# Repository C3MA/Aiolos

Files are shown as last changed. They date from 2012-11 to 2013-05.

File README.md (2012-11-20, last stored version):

avr-template
============

A minimal template for AVR microcontroller projects. Usage:

1. Fork this repository, then rename it to reflect your project
(Admin->Rename on Github)
2. Clone your repository
3. Change the Makefile to reflect your microcontroller, programmer etc.

### License

The UART code is written by Peter Fleury. Everything else: BSD 2-clause
license as below:

Copyright (c) 2012, Mathias Dalheimer
All rights reserved.

Redistribution and use in source and binary forms, with or without
modification, are permitted provided that the following conditions are
met:

* Redistributions of source code must retain the above copyright notice, 
this list of conditions and the following disclaimer.

* Redistributions in binary form must reproduce the above copyright
notice, this list of conditions and the following disclaimer in the
documentation and/or other materials provided with the distribution.

THIS SOFTWARE IS PROVIDED BY THE COPYRIGHT HOLDERS AND CONTRIBUTORS "AS
IS" AND ANY EXPRESS OR IMPLIED WARRANTIES, INCLUDING, BUT NOT LIMITED
TO, THE IMPLIED WARRANTIES OF MERCHANTABILITY AND FITNESS FOR A
PARTICULAR PURPOSE ARE DISCLAIMED. IN NO EVENT SHALL THE COPYRIGHT
HOLDER OR CONTRIBUTORS BE LIABLE FOR ANY DIRECT, INDIRECT, INCIDENTAL,
SPECIAL, EXEMPLARY, OR CONSEQUENTIAL DAMAGES (INCLUDING, BUT NOT
LIMITED TO, PROCUREMENT OF SUBSTITUTE GOODS OR SERVICES; LOSS
OF USE, DATA, OR PROFITS; OR BUSINESS INTERRUPTION) HOWEVER
CAUSED AND ON ANY THEORY OF LIABILITY, WHETHER IN CONTRACT,
STRICT LIABILITY, OR TORT (INCLUDING NEGLIGENCE OR OTHERWISE)
ARISING IN ANY WAY OUT OF THE USE OF THIS SOFTWARE, EVEN IF ADVISED OF
THE POSSIBILITY OF SUCH DAMAGE.

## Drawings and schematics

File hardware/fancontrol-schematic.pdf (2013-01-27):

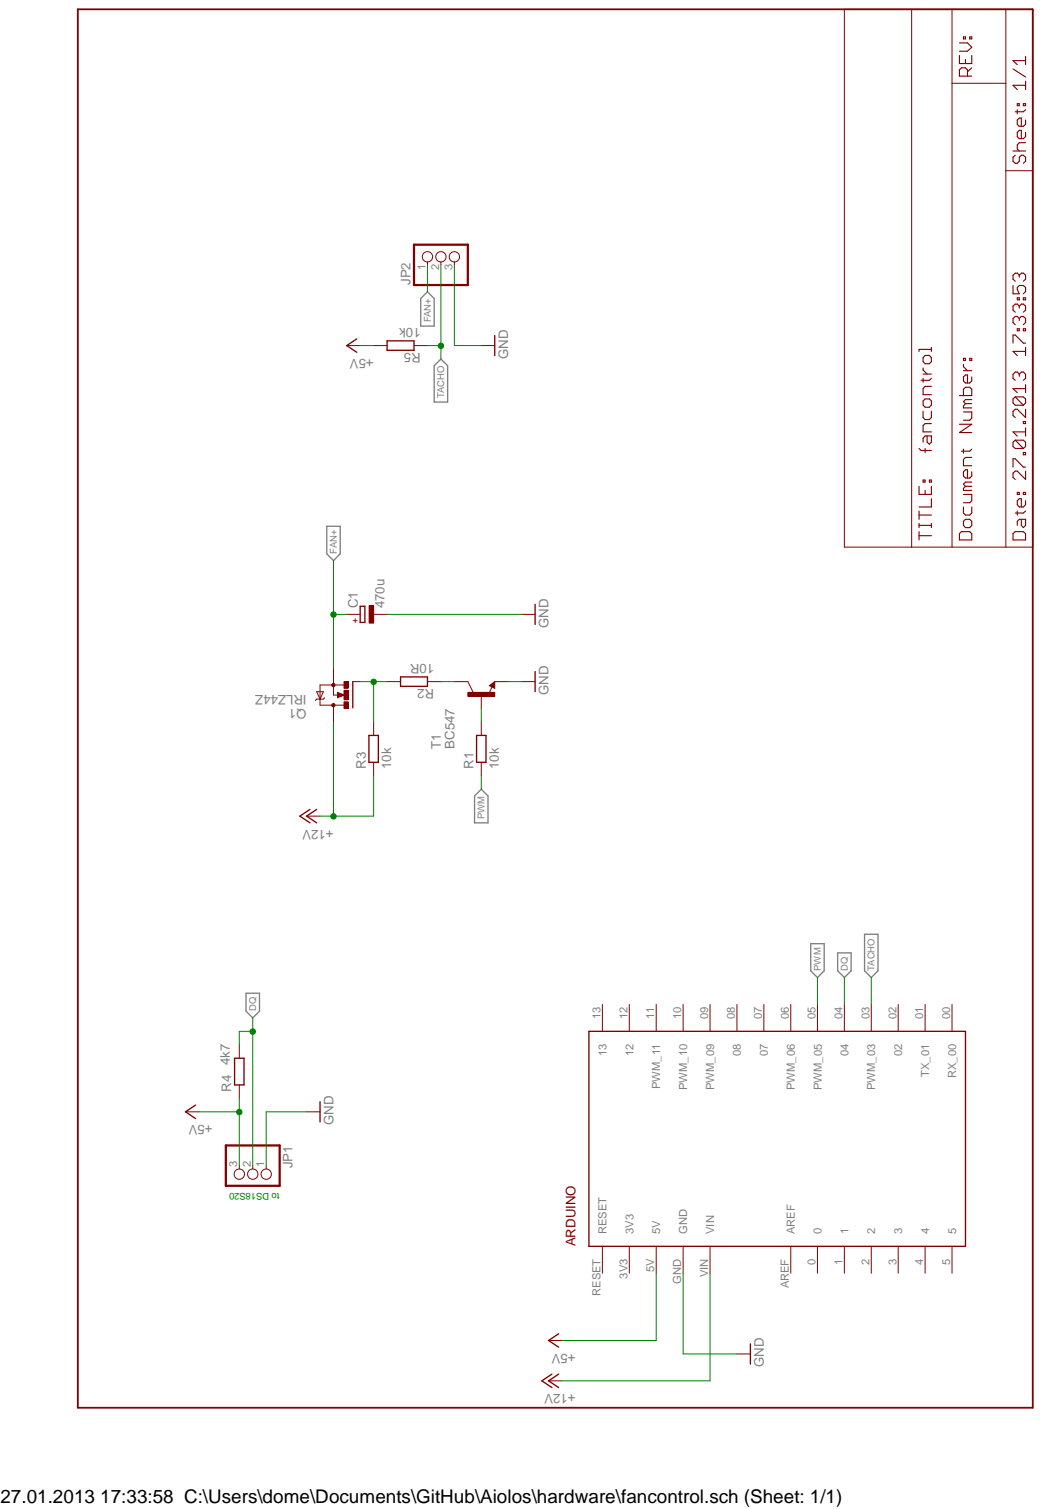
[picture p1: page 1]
GND; RESET RESET; GND GND; VIN VIN; AREF AREF; PWM_11 11; PWM_10 10; PWM_09 09; PWM_06 06; PWM_05 05; PWM_03 03; FAN+; TACHO; PWM; ARDUINO

27.01.2013 17:33:58 C:\Users\dome\Documents\GitHub\Aiolos\hardware\fancontrol.sch (Sheet: 1/1)

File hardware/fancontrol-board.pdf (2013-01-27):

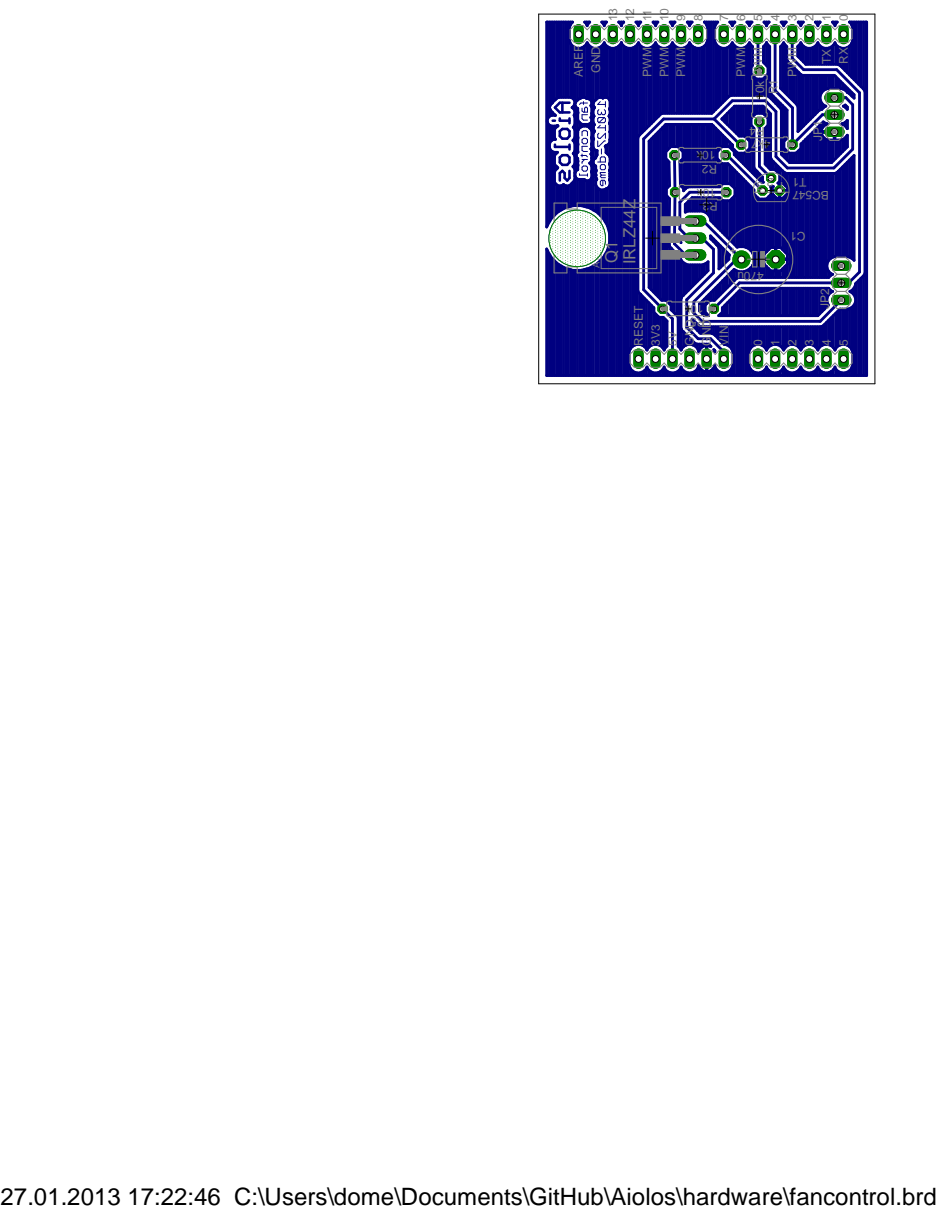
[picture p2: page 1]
27.01.2013 17:22:46 C:\Users\dome\Documents\GitHub\Aiolos\hardware\fancontrol.brd A¹⁷,5mm; RESET; GND GND VIN; AREF; GND; PWM; IRLZ44Z

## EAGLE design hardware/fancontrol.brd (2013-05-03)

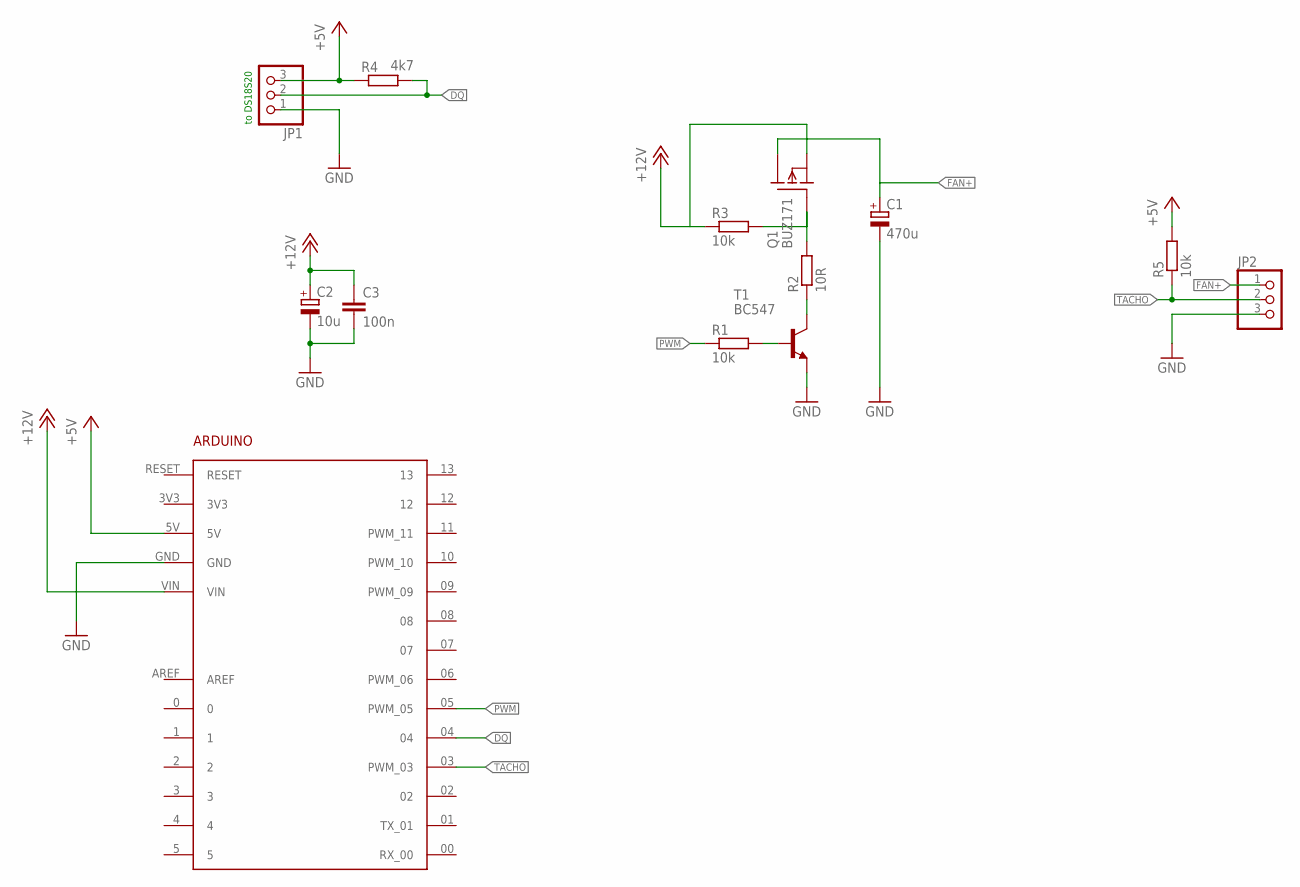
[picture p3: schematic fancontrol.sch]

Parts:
ARDUINO1: ARDUINO
C1: 470u; E5-10,5
C2: 10u; E2,5-5
C3: 100n; C025-025X050
JP1, JP2: PINHD-1X3; 1X03
Q1: BUZ171; TO220
R1, R3, R5: 10k; 0207/7
R2: 10R; 0207/7
R4: 4k7; 0207/7
T1: BC547; TO92

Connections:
+5V: ARDUINO1.5V, JP1.3, R4.1, R5.2
+12V: ARDUINO1.VIN, C2.+, C3.1, Q1.3 (S), R3.1
DQ: ARDUINO1.04, JP1.2, R4.2
FAN+: C1.+, JP2.1, Q1.2 (D)
GND: ARDUINO1.GND, C1.-, C2.-, C3.2, JP1.1, JP2.3, T1.1 (E)
unnamed: R1.2, T1.2 (B)
unnamed: R2.1, T1.3 (C)
unnamed: Q1.1 (G), R2.2, R3.2
PWM: ARDUINO1.05 (PWM_05), R1.1
TACHO: ARDUINO1.03 (PWM_03), JP2.2, R5.1

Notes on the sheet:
to DS18S20

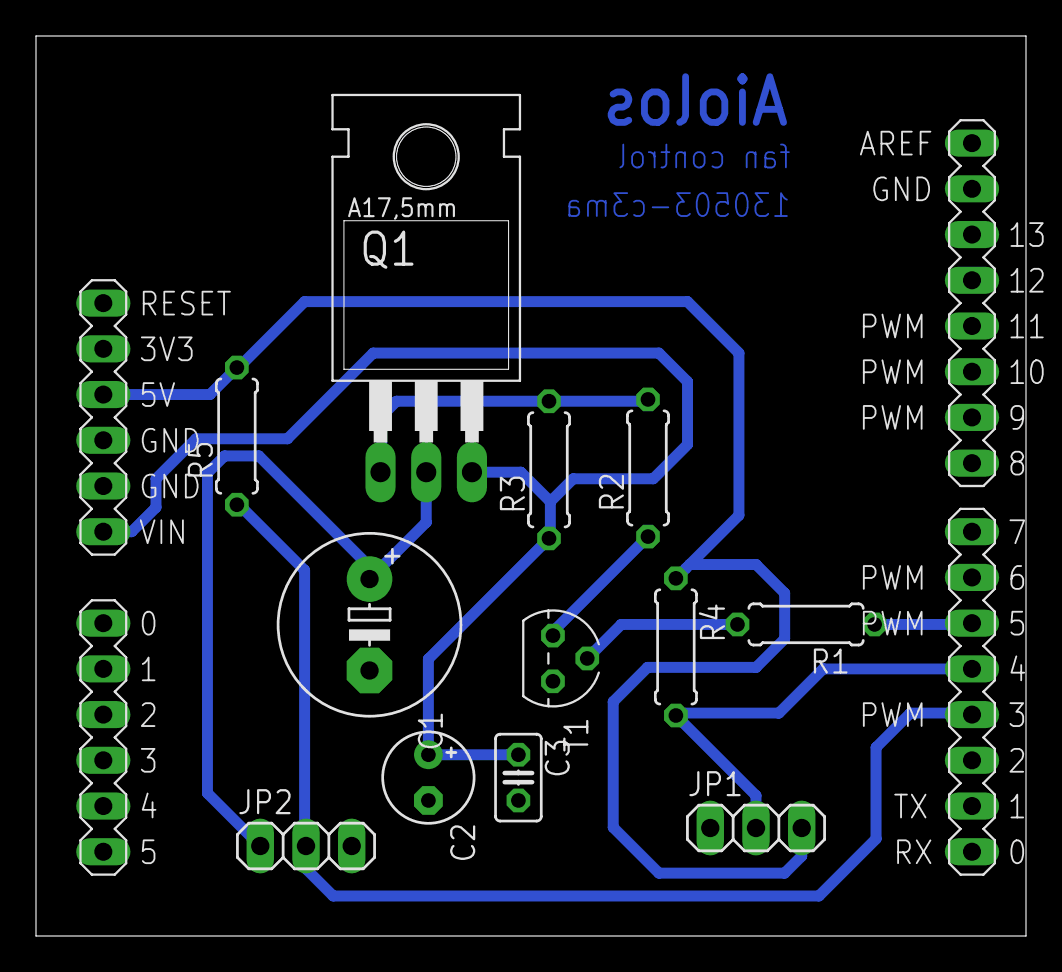
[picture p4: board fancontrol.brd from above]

Board: 2 copper layers, 55.0 x 50.0 mm, 13 parts (0 on the bottom side), 10 nets.

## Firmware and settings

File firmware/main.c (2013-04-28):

#include <stdlib.h>
#include <avr/io.h>
#include <avr/interrupt.h>
#include <avr/pgmspace.h>
#include <stdio.h>



#include "uart.h"
#include "temperature.h"

int uart_putchar( char c, FILE *stream )
{
    if( c == '\n' )
        uart_putchar( '\r', stream );
 
    uart_putc(c);

    return 0;
}

static FILE mystdout = FDEV_SETUP_STREAM( uart_putchar, NULL, _FDEV_SETUP_WRITE );

/* define CPU frequency in Mhz here if not defined in Makefile */
#ifndef F_CPU
#define F_CPU 16000000UL
#endif

/* 115200 baud  Arduino bootlaoder macht das x2 deshalb 57600 */
#define UART_BAUD_RATE      57600      

/* counter for tacho */
volatile uint8_t tachoCounter = 0;

volatile uint8_t flag = 0;


#define Kp 40.0
#define Ki 0.0
#define Kd 0.0

double PID_Berechnung (double x, double w)
{ 
static double ealt;
double e,esum,y; 

e = x - w;                // aktuelle Regelabweichung bestimmen
if ((y < 1023)&&(y > 0))  // bei Übersteuertem stellglied Integration einfrieren
  {                       // (Anti-Windup)
    esum = esum + e;      // Summe der Regelabweichung aktualisieren  
  }
y = (Kp*e)+(Ki*esum)+(Kd*((e-ealt))/1);  // Reglergleichung
ealt = e;                 // Regelabweichung für nächste Abtastung merken
if (y > 256)             // Stellgröße auf 0..1023 begrenzen (10 bit PWM)
  {
    y = 255;
  }
if (y < 1)
  {
    y = 0;
  }
return y;                 // Stellgröße zurückgeben
}

int main(void)
{

    unsigned int c;
    char buffer[7];
    int  num=134;
    
    /*
     * Init Timer 1; 1s cycle
     */
    
    TCCR1A = 0x0;
    TCCR1B = (1<<WGM12) | (1<<CS12) | (1<<CS10);
    OCR1AH = 0x3D;
    OCR1AL = 0x08;
    TIMSK1 |= (1<<OCIE1A);
    
    /* Init PWM */
    PRR &= ~(1<<PRTIM0);
    DDRD |= (1<<PD5); // Port OC0B 
    TCCR0A = (1<<WGM10) | (1<<COM0B1); // PWM, phase correct, 8 bit.
    TCCR0B = (1<<CS12) | (1<<CS10); // Prescaler 1024 = Enable counter
    OCR0B = 240; // Duty cycle 50% (Anm. ob 128 oder 127 bitte prüfen) 
    
    /*
     *  Initialize UART library, pass baudrate and AVR cpu clock
     *  with the macro 
     *  UART_BAUD_SELECT() (normal speed mode )
     *  or 
     *  UART_BAUD_SELECT_DOUBLE_SPEED() ( double speed mode)
     */
    uart_init( UART_BAUD_SELECT(UART_BAUD_RATE,F_CPU) ); 
    stdout = &mystdout;

    /* Init INT 1 Tacho */
    EIMSK |= (1<<INT1);
    EICRA |= (1<<ISC11) | (1<<ISC10); 

    /*
     * now enable interrupt, since UART library is interrupt controlled
     */
    sei();

    temperature_init();

    for(;;)
    {
        if (flag == 1)
	{
	    flag = 0;
	    uint8_t tcount = tachoCounter;
	    tachoCounter = 0;
	    
	    /*if (temp >= 30)
	    {
		OCR0B = 0;
	    } 
	    else if(temp >= 28.0)
	    {
		OCR0B = 200;
	    }
	    else
	    {
		OCR0B = 250;
	    }*/
	   
	    
	    /*
	    if (y < 1)
	    {
	      y = 0;
	    }*/
	    
	    OCR0B = (uint8_t)  PID_Berechnung((double) temperature_get(), 26.0);
	    
	    printf("%s;%d;%d\r\n",temperature_as_string(), tcount * 30, OCR0B);
	    /*
	    printf("Current temp: %s deg C\r\n", temperature_as_string());
	    printf("Current speed: %d rpm\r\n", tcount * 30);
	    */
	}
    }
    
}

ISR(TIMER1_COMPA_vect)
{
   flag = 1;
}

ISR(INT1_vect )
{
  tachoCounter++;
}

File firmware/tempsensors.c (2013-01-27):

/**
 * This file is part of C8H10N4O2.
 *
 * (c) Mathias Dalheimer <md@gonium.net>, 2010
 * This file is based on  Martin Thomas' DS18X20 library
 *  http://gandalf.arubi.uni-kl.de/avr_projects/tempsensor/index.html
 *
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
 */

#include <avr/io.h>
#include <avr/pgmspace.h>
#include <avr/interrupt.h>
#include <string.h>

#include "tempsensors.h"
#include "onewire.h"
#include "ds18x20.h"

uint8_t nSensors, i;
volatile int16_t decicelsius;
volatile int32_t temp_eminus4;
uint8_t error;
uint8_t gSensorIDs[MAXSENSORS][OW_ROMCODE_SIZE];

uint32_t starttime;

uint8_t search_sensors(void) {
  uint8_t i;
  uint8_t id[OW_ROMCODE_SIZE];
  uint8_t diff, nSensors;
  ow_reset();
  nSensors = 0;
  diff = OW_SEARCH_FIRST;
  while ( diff != OW_LAST_DEVICE && nSensors < MAXSENSORS ) {
	DS18X20_find_sensor( &diff, &id[0] );
	if( diff == OW_PRESENCE_ERR ) {
	  break;
	}
	if( diff == OW_DATA_ERR ) {
	  break;
	}
	for ( i=0; i < OW_ROMCODE_SIZE; i++ )
	  gSensorIDs[nSensors][i] = id[i];
	nSensors++;
  }
  return nSensors;
}

void uart_put_temp(int16_t decicelsius) {
  char s[10];
  //uart_put_int( decicelsius );
  printf("%d", (int) decicelsius );
  printf(" deci°C, ");
  DS18X20_format_from_decicelsius( decicelsius, s, 10 );
  printf( s );
  printf(" °C");
}

int16_t getTemperature(void) {
  return decicelsius;
}

int32_t getHighResTemperature(void) {
  return temp_eminus4;
}

float getTemperatureFloat(void) {
  return (temp_eminus4/10000.0);
}
#if DS18X20_MAX_RESOLUTION

void uart_put_temp_maxres(int32_t tval) {
  char s[10];

  //uart_put_longint( tval );
  printf("%d", (int )tval );
  printf(" °Ce-4, ");
  DS18X20_format_from_maxres( tval, s, 10 );
  printf( s );
  printf(" °C");
}

#endif /* DS18X20_MAX_RESOLUTION */

uint8_t initTempSensors(void) {
  printf("Searching for OneWire temperature sensors.\n" );
  nSensors = search_sensors();
  return nSensors;
}	

void loopTempSensors(void) {
  error = 0;

  if ( nSensors == 0 ) {
    error++;
  }

  if ( DS18X20_start_meas( DS18X20_POWER_PARASITE, NULL ) 
      == DS18X20_OK) {

    for ( i = 0; i < nSensors; i++ ) {
      if ( DS18X20_read_maxres( &gSensorIDs[i][0], &temp_eminus4 )
          == DS18X20_OK ) {
        ;; // we're cool - read a value.
        //uart_put_temp_maxres( temp_eminus4 );
      }
      else {
        error++;
      }
    }
  } else {
    error++;
  }

  if ( error ) {
    nSensors = search_sensors();
    //uart_put_int( (int) nSensors );
    error = 0;
  }
}

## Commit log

2013-01-27 first prototype firmware for the temperature control of der Schrank
2013-01-27 empty schematic
    [fancontrol.sch]
2013-01-27 fan control
    [fancontrol.sch]
2013-01-27 generated board
    [fancontrol.brd, fancontrol.sch]
2013-01-27 populated the pcb
    [fancontrol.brd, fancontrol.sch]
2013-01-27 finished the routung
    [fancontrol.brd]
2013-01-27 added version number
    [fancontrol.brd]
2013-01-27 changed R2 from 10k to 10R
    [fancontrol.brd, fancontrol.sch]
2013-02-20 connect JP2 to GND. Fixes #2
    [fancontrol.brd, fancontrol.sch]
2013-02-20 added capacitors to Vin. Fixes #1
    [fancontrol.brd, fancontrol.sch]
2013-04-28 Added Tachosignal and PID
2013-05-03 Replace transistor, make routes wider
    [fancontrol.brd, fancontrol.sch]
2013-05-03 Fix one wire to make GND work again
    [fancontrol.brd]

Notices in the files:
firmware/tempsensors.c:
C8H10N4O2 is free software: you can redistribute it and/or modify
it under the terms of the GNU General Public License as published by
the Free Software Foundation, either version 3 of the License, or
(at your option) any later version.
